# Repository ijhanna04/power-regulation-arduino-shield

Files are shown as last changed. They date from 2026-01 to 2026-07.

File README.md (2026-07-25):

# Power Regulation + LED Arduino Shield (Altium)

## Overview
A 2-layer Arduino Uno shield design that accepts a 12V DC input, uses a
TPS562201 buck regulator to generate a nominal 5V rail, and distributes 12V to
two 12V-rated SMD LED modules in parallel.

This project demonstrates an end-to-end PCB workflow: requirements → schematic →
PCB layout → DRC/DFM cleanup → fabrication-document generation.

## Requirements (Design Targets)
- Input: 12V DC
- Regulated output: 5V DC
- Efficiency target: ≥ 90% (not yet validated by measurement)
- Load: Arduino Uno + 2× high-power SMD LEDs (≥10W each) in parallel
- Form factor: Arduino Uno shield using standard pin headers
- Components placed on top layer only
- Standard board thickness (~62 mil), 2-layer stackup

## Architecture
- +12V path: input connector → LED bank (parallel) + regulator input
- +5V path: regulator output → Arduino Uno 5V header pin
- Ground strategy: bottom-layer ground pour for low impedance returns

## Implementation Notes
- Switching regulator selected to meet efficiency target
- Pin header footprints / symbols may be custom-built (Arduino shield pattern)
- Power rails implemented with polygon pours for current capacity

## Repo Layout
- `hardware/altium/` – Altium project (schematic + PCB)
- `docs/` – schematic PDF + draft fabrication/assembly drawing
- `outputs/` – Gerber layers, BOM, pick-and-place data, and drill report
- `media/` – screenshots (schematic, layout, 3D render)

## How to Review
1. Start with `docs/` for schematic + drawings
2. Inspect `media/` for layout decisions (polygons, ground pour, placement)
3. Use `outputs/` to review the exported Gerber layers, BOM, and placement data

## Validation status

- Schematic, PCB layout, and fabrication drawings are provided for design review
- The fabrication/assembly drawing is explicitly marked as a draft and still
  contains template notes that must be finalized
- The efficiency target has not been verified by bench measurement
- The repository does not currently include an Excellon drill file or ODB++ package
- The output set should be regenerated and reviewed before ordering boards
- When powering an Arduino through its 5V header, avoid connecting another active
  5V source unless the board's power-path behavior has been verified

## Design Screenshots

### Schematic
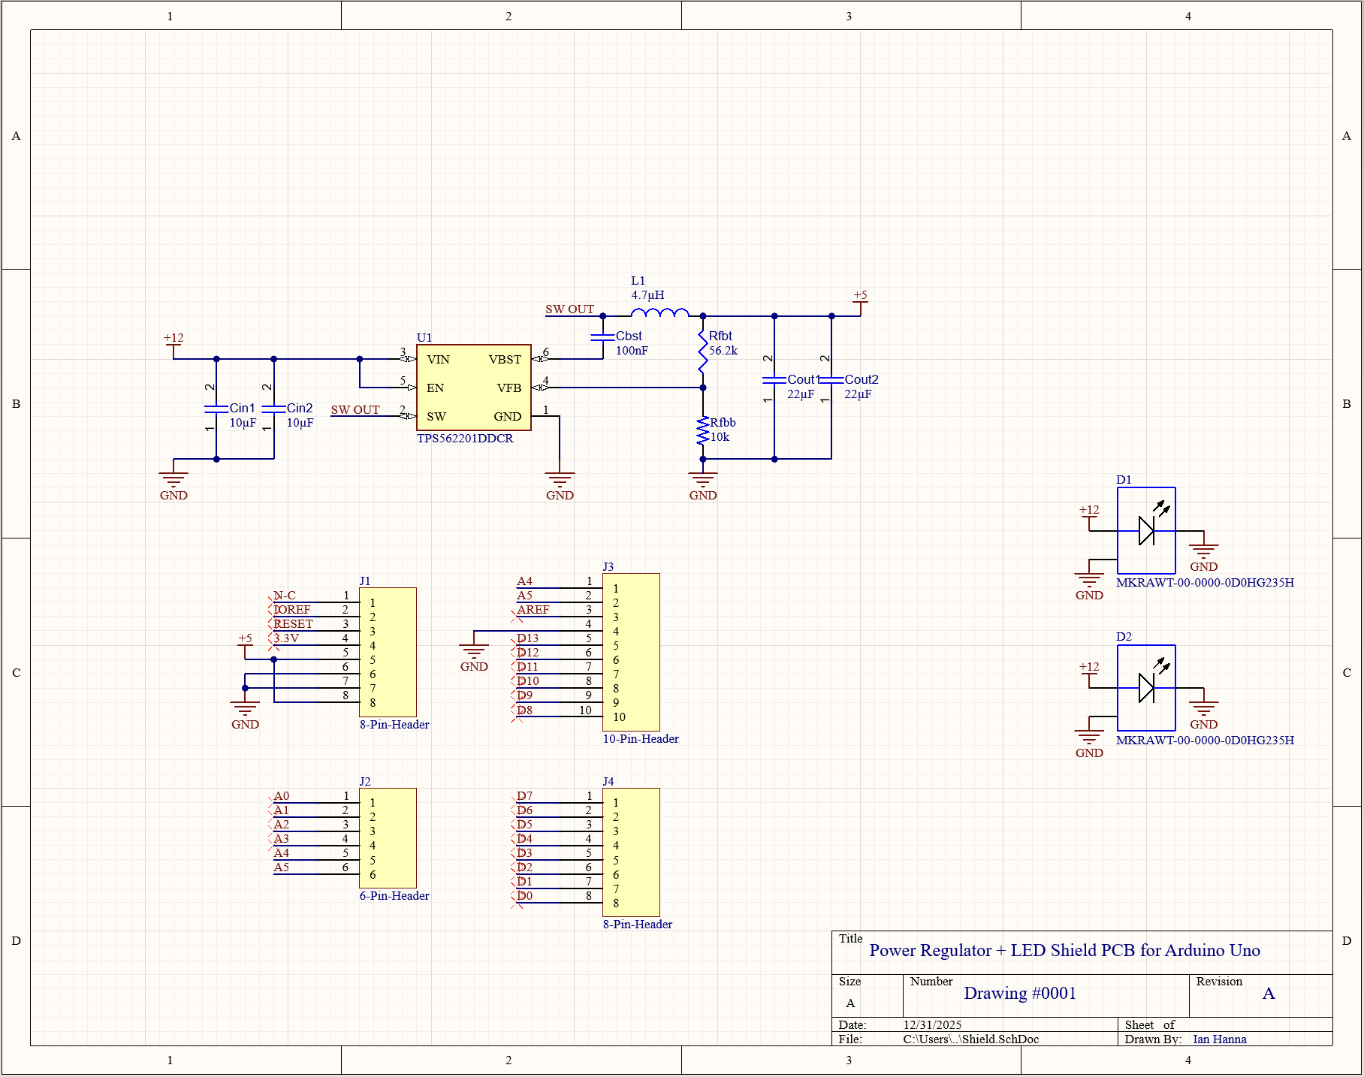
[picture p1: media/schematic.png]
Schematic


### PCB Layout
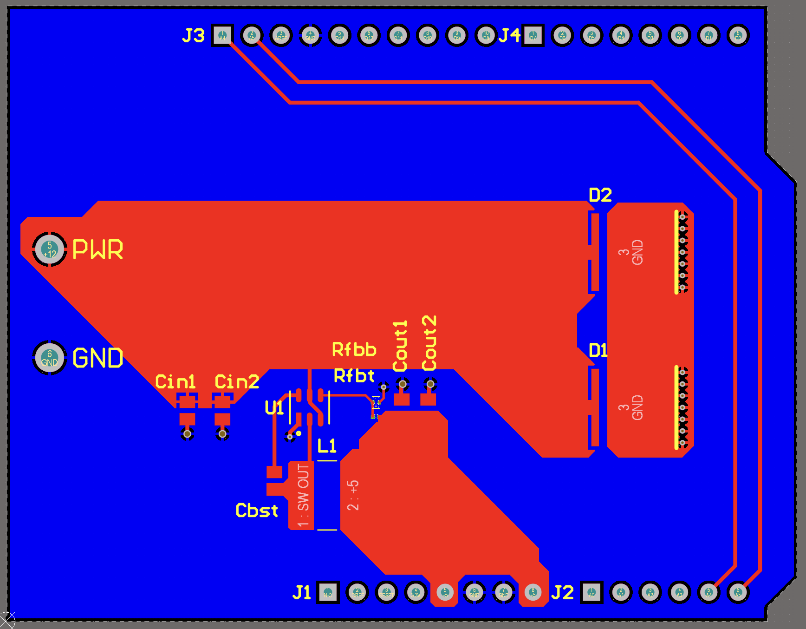
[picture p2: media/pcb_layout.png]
PCB Layout


### 3D View
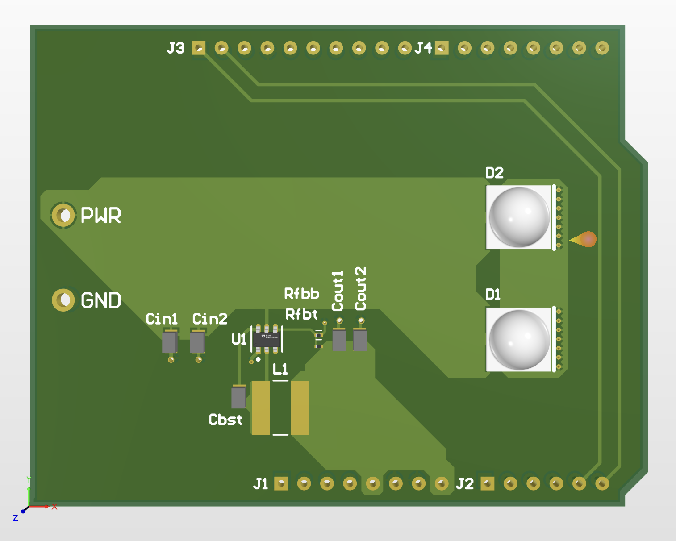
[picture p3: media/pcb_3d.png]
3D PCB Render


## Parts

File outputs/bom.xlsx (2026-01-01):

Comment | Description | Designator | Footprint | LibRef | Quantity
08053C104KAT2A | 0805 100 nF 25V ±10 % Tolerance X7R Surface Mount Multilayer Ceramic Capacitor | Cbst | C0805 | CMP-001-00084-2 | 1
MSAST219LB5106KTNA01 | Ceramic Capacitor, Multilayer, Ceramic, 25V, 10% +Tol, 10% -Tol, X5R, 15% TC, 10uF, Surface Mount, 0805 | Cin1, Cin2 | C0805 | CMP-001-00083-2 | 2
MSASL219LB5226MTNA01 | Ceramic Capacitor, Multilayer, Ceramic, 10V, 20% +Tol, 20% -Tol, X5R, 15% TC, 22uF, Surface Mount, 0805 | Cout1, Cout2 | C0805 | CMP-001-00085-3 | 2
MKRAWT-00-0000-0D0HG235H | LED, White, 12 V, 2-Pin SMD, RoHS, Tape and Reel | D1, D2 | CREE-MK-R-2_V | CMP-2100-00977-1 | 2
8-Pin-Header |  | J1, J4 | 8-Pin-Header-Footprint-1 | CMP-00004-1 | 2
6-Pin-Header |  | J2 | 6-Pin-Header-Footprint-1 | CMP-00003-1 | 1
10-Pin-Header |  | J3 | 10-Pin-Header-Footprint-1 | CMP-00005-2 | 1
SRN6045-4R7Y | Inductor Power Semi-Shielded Wirewound 4.7uH 30% 100KHz 15Q-Factor Ferrite 3A 37.6mOhm DCR T/R | L1 | SRN6045 | CMP-006-00021-2 | 1
RC0201FR-0710KL | 10 kOhms Â±1% 0.05W, 1/20W Chip Resistor 0201 (0603 Metric) Moisture Resistant Thick Film | Rfbb | RESC0603X26N | CMP-009-00197-1 | 1
RC0201FR-0756K2L | Res Thick Film 0201 56.2K Ohm 1% 0.05W(1/20W) ±200ppm/C Molded SMD Paper T/R | Rfbt | RESC0603X26N | CMP-009-00178-2 | 1
TPS562201DDCR | IC REG BUCK ADJ 2A TSOT23-6 | U1 | FP-DDC0006A-IPC_C | CMP-04918-000361-1 | 1

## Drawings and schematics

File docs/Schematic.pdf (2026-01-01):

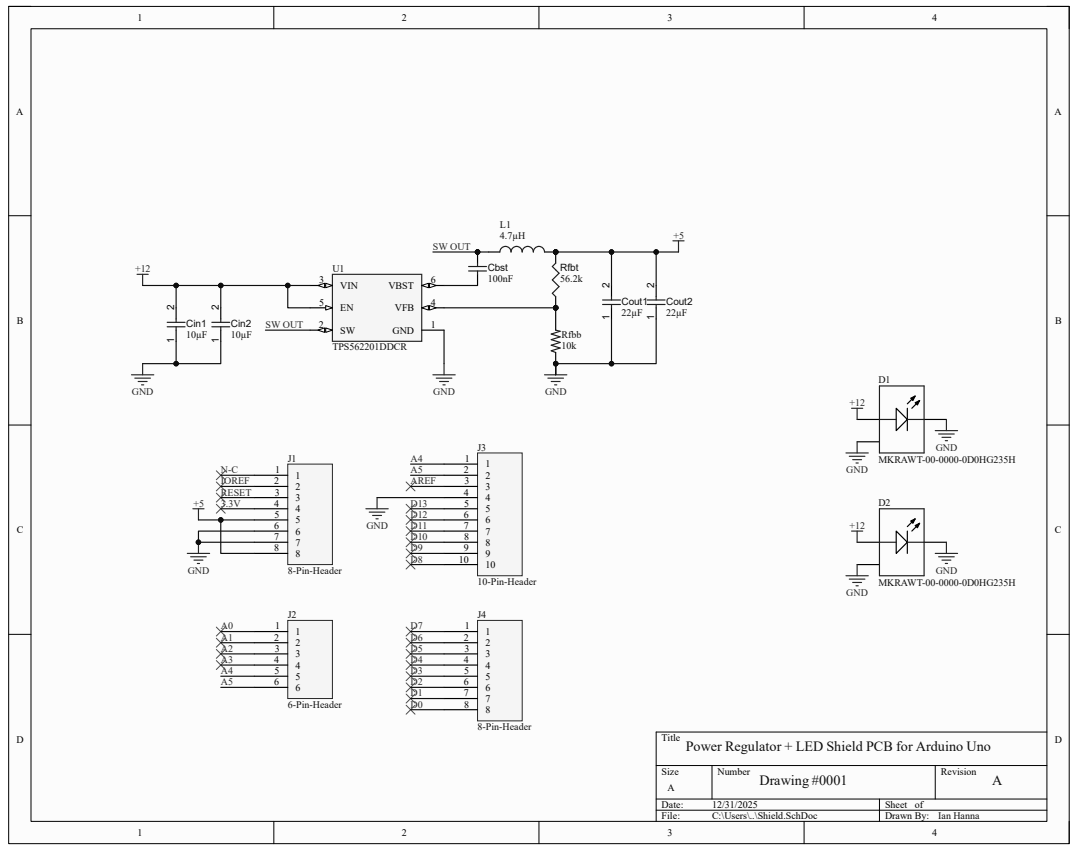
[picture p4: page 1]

Title
Power Regulator + LED Shield PCB for Arduino Uno

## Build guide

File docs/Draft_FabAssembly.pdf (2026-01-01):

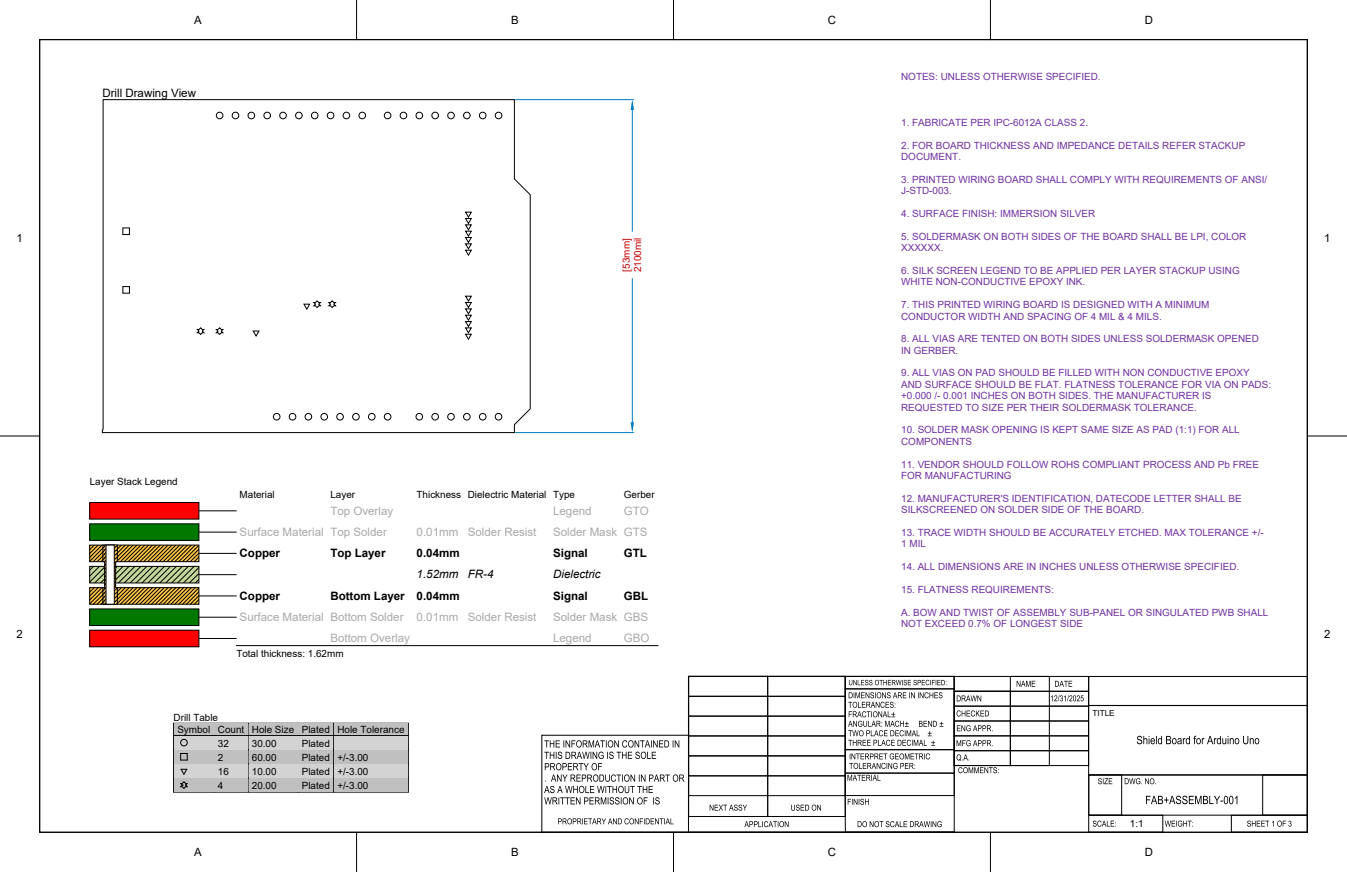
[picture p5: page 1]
Drill Table; TITLE; 15. FLATNESS REQUIREMENTS:; Material; Layer; Thickness Dielectric Material Type; Gerber; Top Overlay; Legend; GTO; Surface Material Top Solder; 0.01mm Solder Resist; Solder Mask GTS; Copper; Top Layer; Signal; GTL; Dielectric; Bottom Layer 0.04mm; GBL; Surface Material Bottom Solder 0.01mm Solder Resist; Solder Mask GBS; Bottom Overlay; GBO; Total thickness: 1.62mm; 2100mil

NOTES: UNLESS OTHERWISE SPECIFIED.

Drill Drawing View

1. FABRICATE PER IPC-6012A CLASS 2.

2. FOR BOARD THICKNESS AND IMPEDANCE DETAILS REFER STACKUP
DOCUMENT.

3. PRINTED WIRING BOARD SHALL COMPLY WITH REQUIREMENTS OF ANSI/
J-STD-003.

4. SURFACE FINISH: IMMERSION SILVER

5. SOLDERMASK ON BOTH SIDES OF THE BOARD SHALL BE LPI, COLOR
XXXXXX.

6. SILK SCREEN LEGEND TO BE APPLIED PER LAYER STACKUP USING
WHITE NON-CONDUCTIVE EPOXY INK.

7. THIS PRINTED WIRING BOARD IS DESIGNED WITH A MINIMUM
CONDUCTOR WIDTH AND SPACING OF 4 MIL & 4 MILS.

8. ALL VIAS ARE TENTED ON BOTH SIDES UNLESS SOLDERMASK OPENED
IN GERBER.

9. ALL VIAS ON PAD SHOULD BE FILLED WITH NON CONDUCTIVE EPOXY
AND SURFACE SHOULD BE FLAT. FLATNESS TOLERANCE FOR VIA ON PADS:
+0.000 /- 0.001 INCHES ON BOTH SIDES. THE MANUFACTURER IS
REQUESTED TO SIZE PER THEIR SOLDERMASK TOLERANCE.

10. SOLDER MASK OPENING IS KEPT SAME SIZE AS PAD (1:1) FOR ALL
COMPONENTS

11. VENDOR SHOULD FOLLOW ROHS COMPLIANT PROCESS AND Pb FREE
FOR MANUFACTURING

Layer Stack Legend

12. MANUFACTURER'S IDENTIFICATION, DATECODE LETTER SHALL BE
SILKSCREENED ON SOLDER SIDE OF THE BOARD.

13. TRACE WIDTH SHOULD BE ACCURATELY ETCHED. MAX TOLERANCE +/-
1 MIL

14. ALL DIMENSIONS ARE IN INCHES UNLESS OTHERWISE SPECIFIED.

A. BOW AND TWIST OF ASSEMBLY SUB-PANEL OR SINGULATED PWB SHALL
NOT EXCEED 0.7% OF LONGEST SIDE

Symbol | Count | Hole Size | Plated | Hole Tolerance

32 | 30.00 | Plated
2 | 60.00 | Plated | +/-3.00
16 | 10.00 | Plated | +/-3.00
4 | 20.00 | Plated | +/-3.00

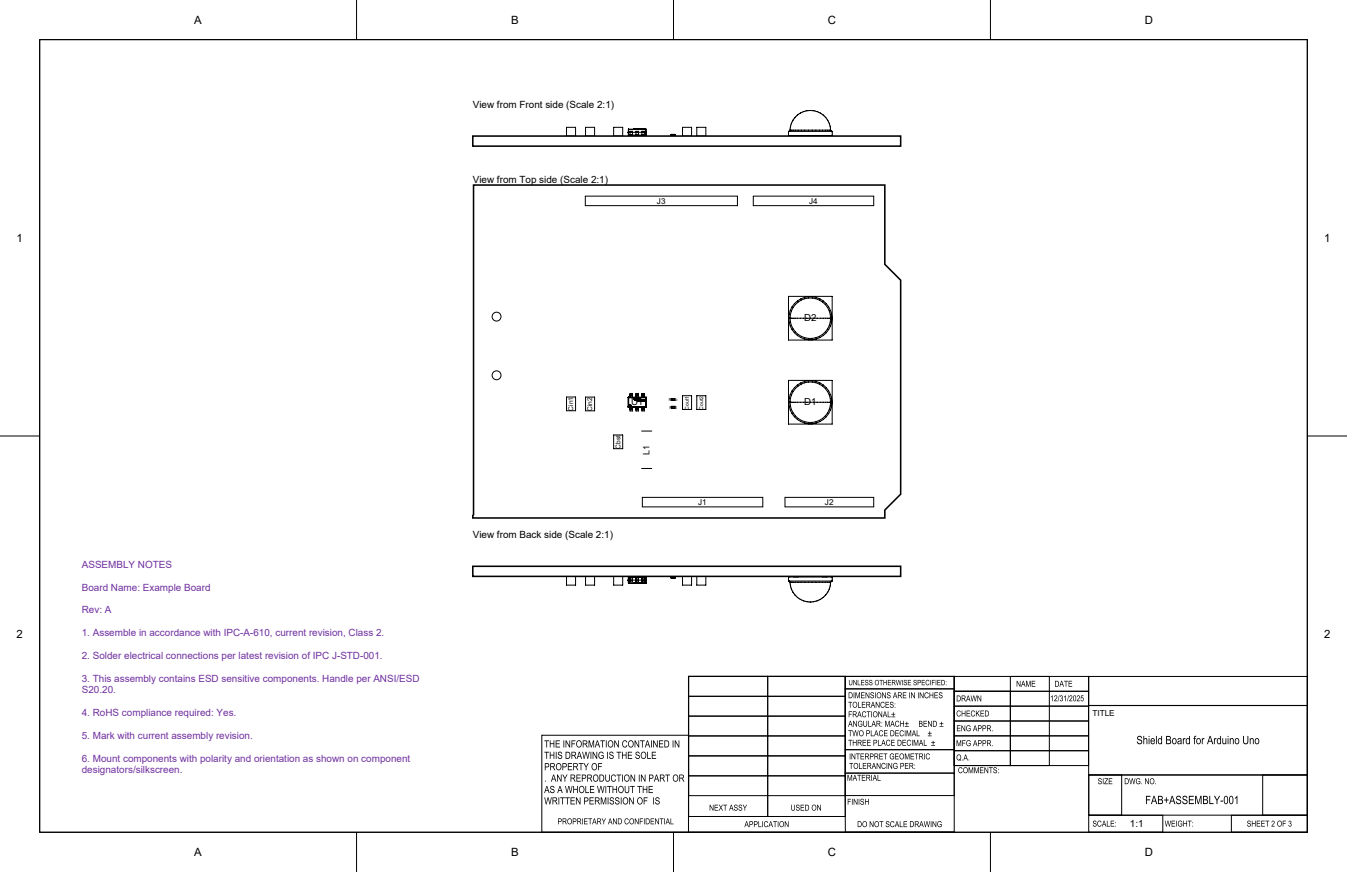
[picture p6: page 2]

View from Front side (Scale 2:1)

View from Top side (Scale 2:1)

View from Back side (Scale 2:1)

Board Name: Example Board

1. Assemble in accordance with IPC-A-610, current revision, Class 2.

2. Solder electrical connections per latest revision of IPC J-STD-001.

3. This assembly contains ESD sensitive components. Handle per ANSI/ESD

4. RoHS compliance required: Yes.

5. Mark with current assembly revision.

6. Mount components with polarity and orientation as shown on component
designators/silkscreen.

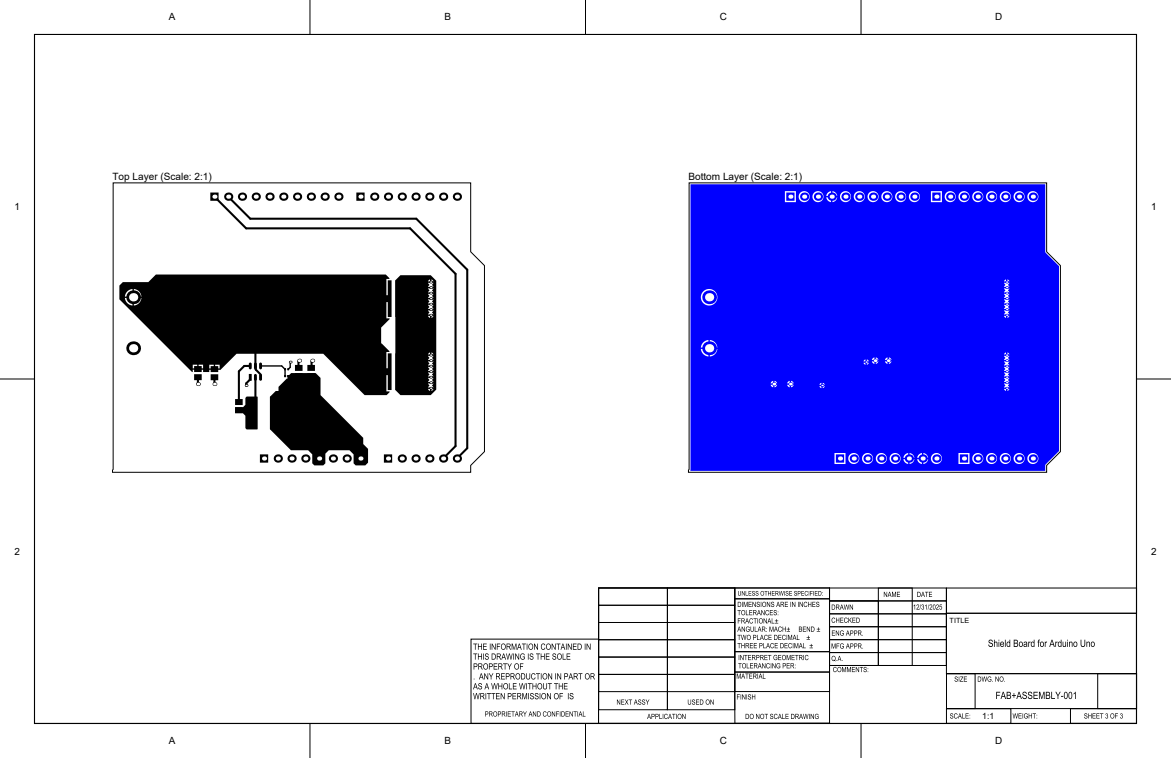
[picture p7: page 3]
Top Layer (Scale: 2:1); Bottom Layer (Scale: 2:1); TITLE

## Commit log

2026-01-01 Add power regulation and LED schematic
    [Shield.SchDoc]
2026-01-01 Add PCB layout with power routing and ground plane
    [ShieldBoard.PcbDoc, ShieldBoard.PrjPcb]
2026-01-01 Add schematic and design documentation
2026-01-01 Added Bill of Materials
    [BOM.xlsx]
2026-01-01 Added Pick and Place
    [Pick Place for ShieldBoard.csv]
2026-01-01 Added Gerbers
    [ShieldBoard.GBL, ShieldBoard.GBO, ShieldBoard.GBP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]
2026-01-01 Update and rename outputs/ShieldBoard.GBL to outputs/gerbers/ShieldBoard.GBL
    [ShieldBoard.GBL]
2026-01-01 Update ShieldBoard.GBO in outputs/gerbers
    [ShieldBoard.GBO]
2026-01-01 Add ShieldBoard.GBP to outputs/gerbers directory
    [ShieldBoard.GBP]
2026-01-01 Update ShieldBoard.GBS file location
    [ShieldBoard.GBS]
2026-01-01 Add ShieldBoard.GM to outputs/gerbers directory
2026-01-01 Update and rename outputs/ShieldBoard.GTL to outputs/gerbers/ShieldBoard.GTL
    [ShieldBoard.GTL]
2026-01-01 Update ShieldBoard.GTO file path
    [ShieldBoard.GTO]
2026-01-01 Update ShieldBoard.GTP file location
    [ShieldBoard.GTP]
2026-01-01 Move ShieldBoard.GTS to outputs/gerbers directory
    [ShieldBoard.GTS]
2026-01-01 Uploaded Drill Files
2026-01-01 Rename Pick Place for ShieldBoard.csv to pick_and_place.csv
    [pick_and_place.csv]
2026-01-01 Added Schematic.pdf
2026-01-01 Upload schematic and pcb media
2026-07-25 Clarify PCB validation and fabrication status
    [pick_and_place.csv]
